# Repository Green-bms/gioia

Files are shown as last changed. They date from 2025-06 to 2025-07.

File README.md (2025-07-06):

# Gioia - glittering fashion
Electronic wearable device <br> 
<br> 
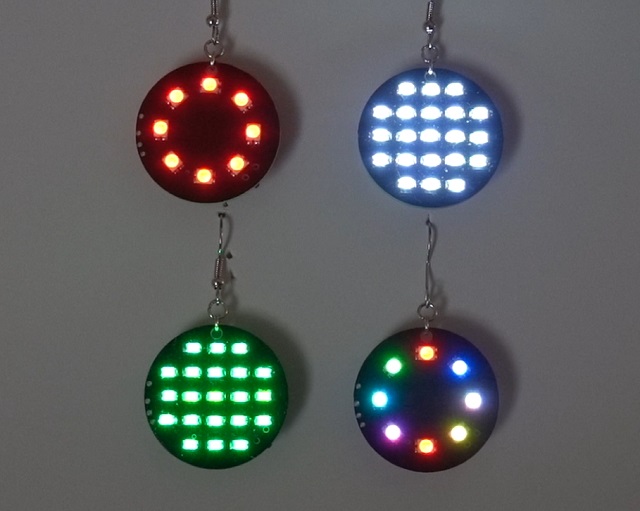
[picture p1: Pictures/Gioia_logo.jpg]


Youtube: https://youtu.be/MnyeiMZdmjQ?si=YpLxnYz4cA8ocs8j <br> 
Instructables: https://www.instructables.com/Gioia-Glittering-Fashion/ <br> 
Hackaday.io: https://hackaday.io/project/202226-gioia-glittering-fashion <br> 
Hackster.io: https://www.hackster.io/green-bms/gioia-glittering-fashion-81f5f8 <br> 
Purchase PCB here: <br> 
https://www.pcbway.com/project/shareproject/Gioia_glittering_fashion_21_monocrome_leds_caeb9192.html  <br>
https://www.pcbway.com/project/shareproject/Gioia_glittering_fashion_8_RGB_leds_abd15673.html <br>

## Description
"Gioia" in Italian means joy.<br> 
I wanted to call this project this way in the hope that it will bring joy and happiness to those who wear it.<br> 
This gadget of 3 cm of diametrer can contain a maximum of 24 single-color LEDs or 8 RGB LEDs.<br> 
The infinite animations, which also include letters and symbols, are managed by an Attiny85 microcontroller.<br> 

### The PCB
Gioia's PCBs are made by PCBway https://pcbway.com/g/kY6w10 <br>
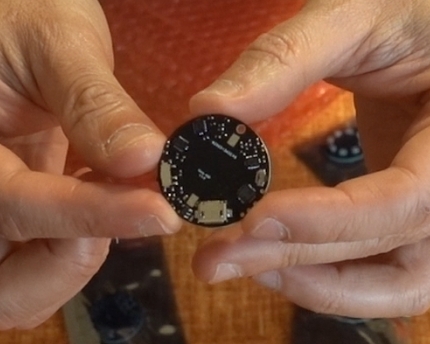
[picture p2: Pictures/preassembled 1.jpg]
 <br>
I chose this supplier because the quality of the PCB and the assembly of the components is of great quality.
The assistance is excellent and the delivery times are always respected <br>
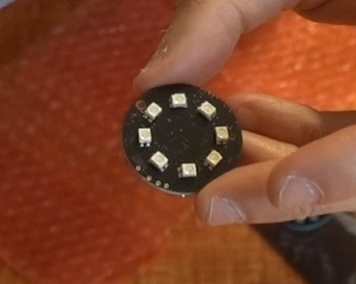
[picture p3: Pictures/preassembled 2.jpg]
 <br>

### Battery
The device is powered by a 30mAh LIR1632 rechargeable lithium battery. <br>
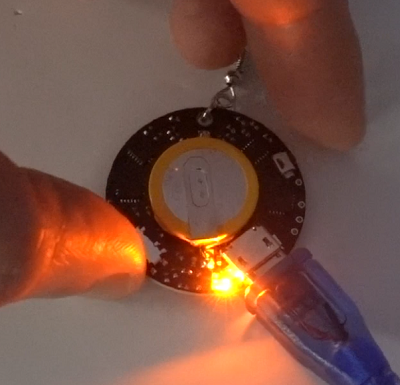
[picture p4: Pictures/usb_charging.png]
 <br> 
Charging is done via a micro USB connector and takes about 90 minutes from 0% to 100%
The device lasts for about 5 continuous hours

### Versions
The project is available in 2 versions:<br>

#### 21 monochrome leds:<br>
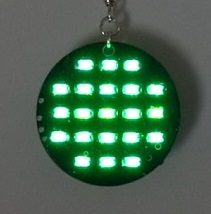
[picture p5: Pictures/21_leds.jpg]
 <br> 
All the documentation to make it is available here: https://github.com/Green-bms/gioia/tree/master/21%20monochrome%20leds%20version

#### 8 RGB leds:<br>
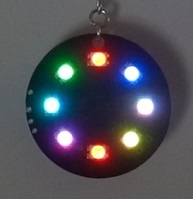
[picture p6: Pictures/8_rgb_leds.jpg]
 <br> 
Each LED can light up in one of these 7 colors: red, green, blue, yellow, fuchsia, aqua, white. <br>
All the documentation to make it is available here: https://github.com/Green-bms/gioia/tree/master/8%20RGB%20leds%20version

### Microcontroller
The device's LEDs are driven by an Attiny85 microcontroller and 3 74HC595 shift registers.<br> 
The LED animations that can compose various light games, texts and symbols, are programmed in the code to be loaded into the microcontroller<br> 
Programming the microcontroller is very simple: you need to power the device via USB and connect the 4 pins of the ISP programmer to the pads shown in the pictures below.<br> 
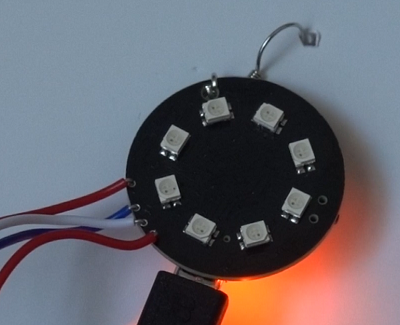
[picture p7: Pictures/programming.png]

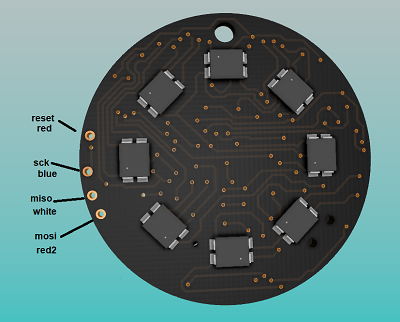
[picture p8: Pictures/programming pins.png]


## Open source Development applications
The project was created using the following Open source applications:
- **KiCad** : to design pcb
- **Arduino IDE** : to design the code for Attiny85 microcontroller of device animations

## Warning
This project is not commercial. This project is for educational and technological purposes.
No warrenty is foreseen.
Green BMS assumes no responsibility for any errors or inaccuracies that may appear in any documentation or file or any software that may be provided.
The use of this project is done entirely at your own risk and responsibility.
The use of this project may not be compliant with local laws or regulations.

## License

This work is licensed under a **Creative Commons Attribution-ShareAlike 4.0 International License**.
https://creativecommons.org/licenses/by-sa/4.0/

### You are free to:

**Share** — copy and redistribute the material in any medium or format

**Adapt**  — remix, transform, and build upon the material
for any purpose, even commercially.
This license is acceptable for Free Cultural Works.
The licensor cannot revoke these freedoms as long as you follow the license terms.

### Under the following terms:

**Attribution** — You must give appropriate credit, provide a link to the license, and indicate if changes were made. You may do so in any reasonable manner, but not in any way that suggests the licensor endorses you or your use.

**ShareAlike** — If you remix, transform, or build upon the material, you must distribute your contributions under the same license as the original.

**No additional restrictions** — You may not apply legal terms or technological measures that legally restrict others from doing anything the license permits.

### Notices:
You do not have to comply with the license for elements of the material in the public domain or where your use is permitted by an applicable exception or limitation.
No warranties are given. The license may not give you all of the permissions necessary for your intended use. For example, other rights such as publicity, privacy, or moral rights may limit how you use the material.

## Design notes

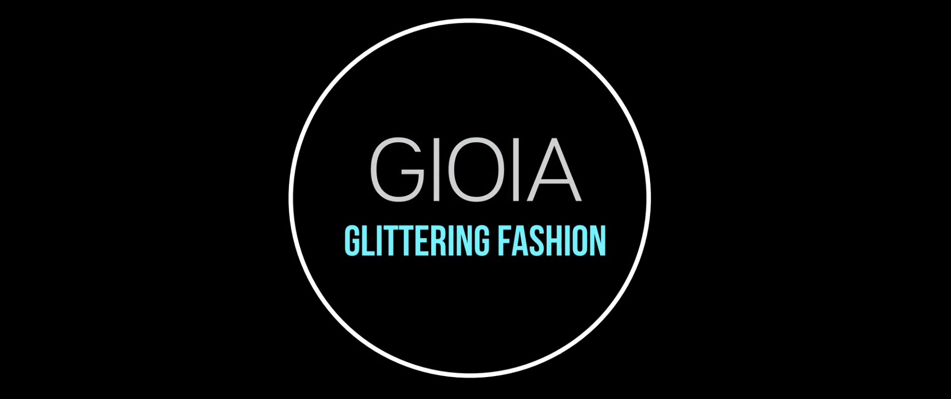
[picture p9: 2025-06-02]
21 monochrome leds version/Kicad files/cartiglio/Immagine.png

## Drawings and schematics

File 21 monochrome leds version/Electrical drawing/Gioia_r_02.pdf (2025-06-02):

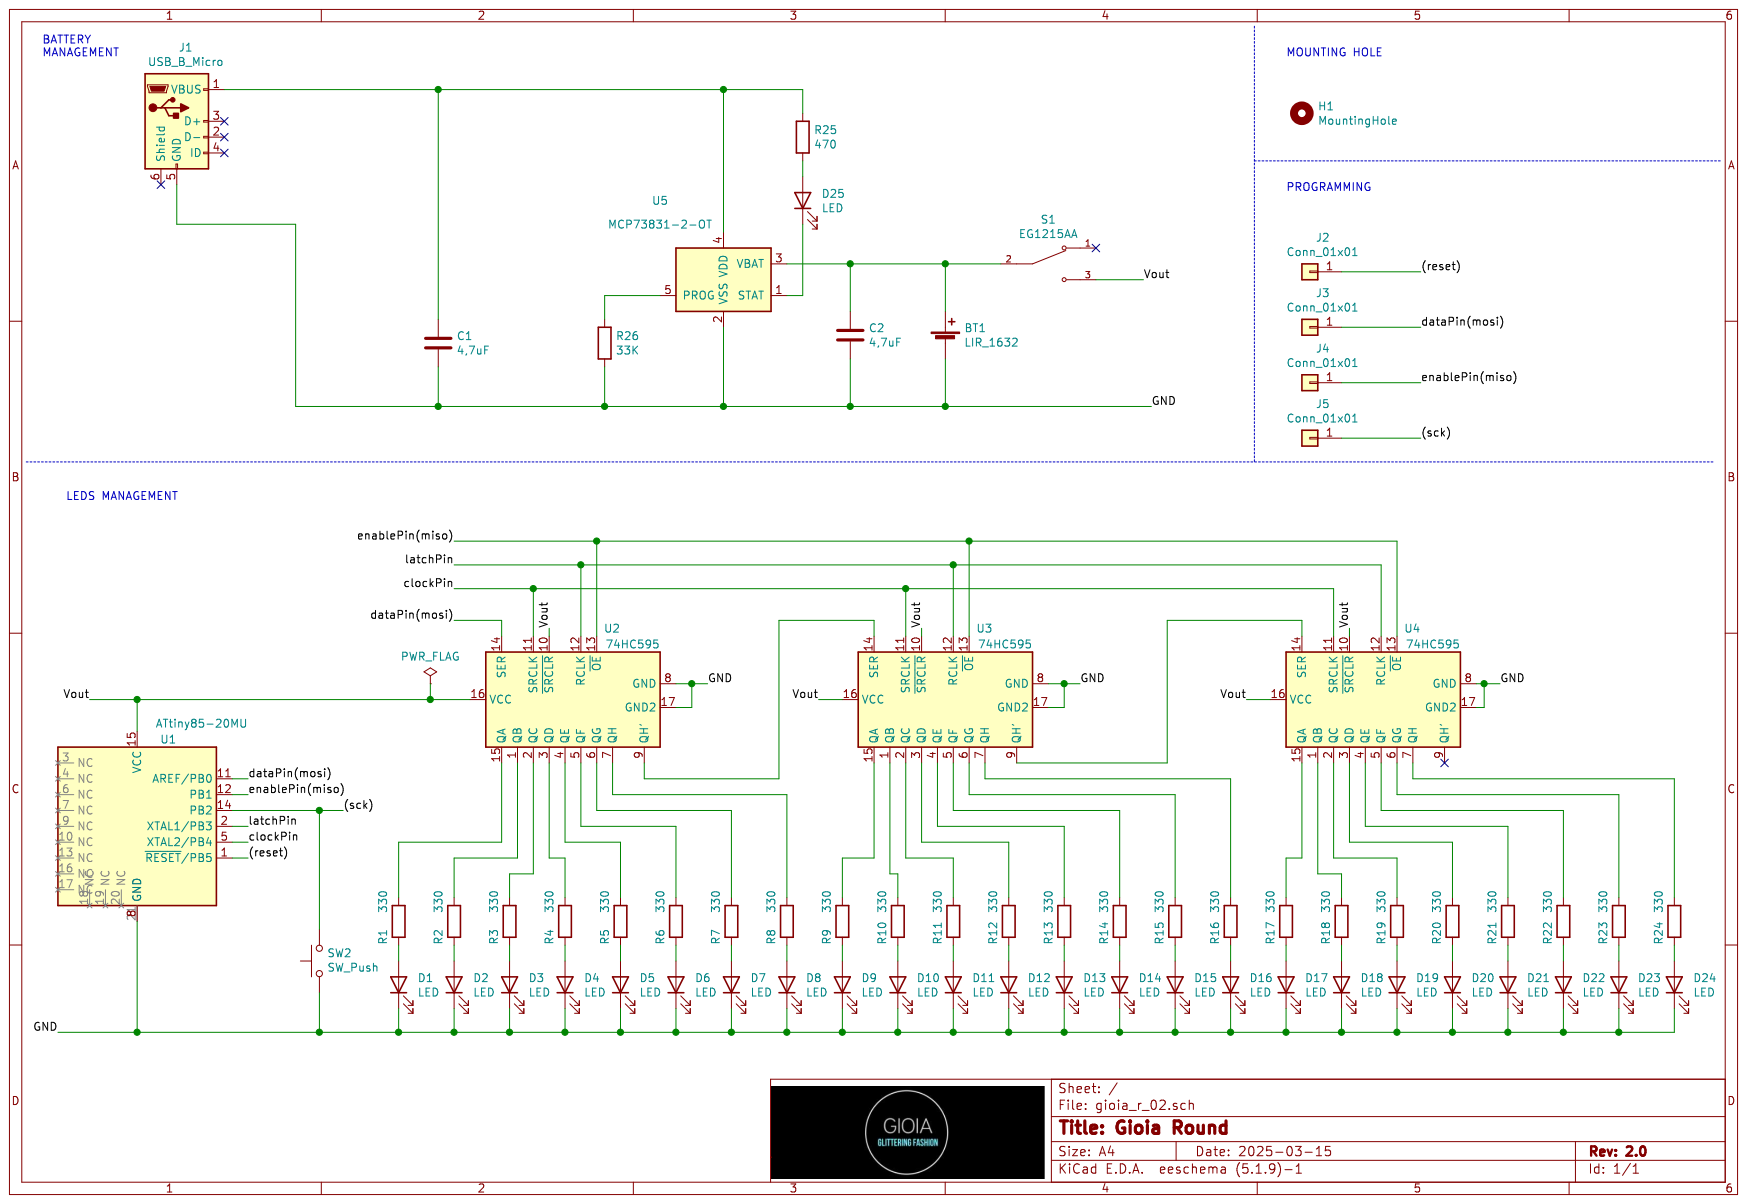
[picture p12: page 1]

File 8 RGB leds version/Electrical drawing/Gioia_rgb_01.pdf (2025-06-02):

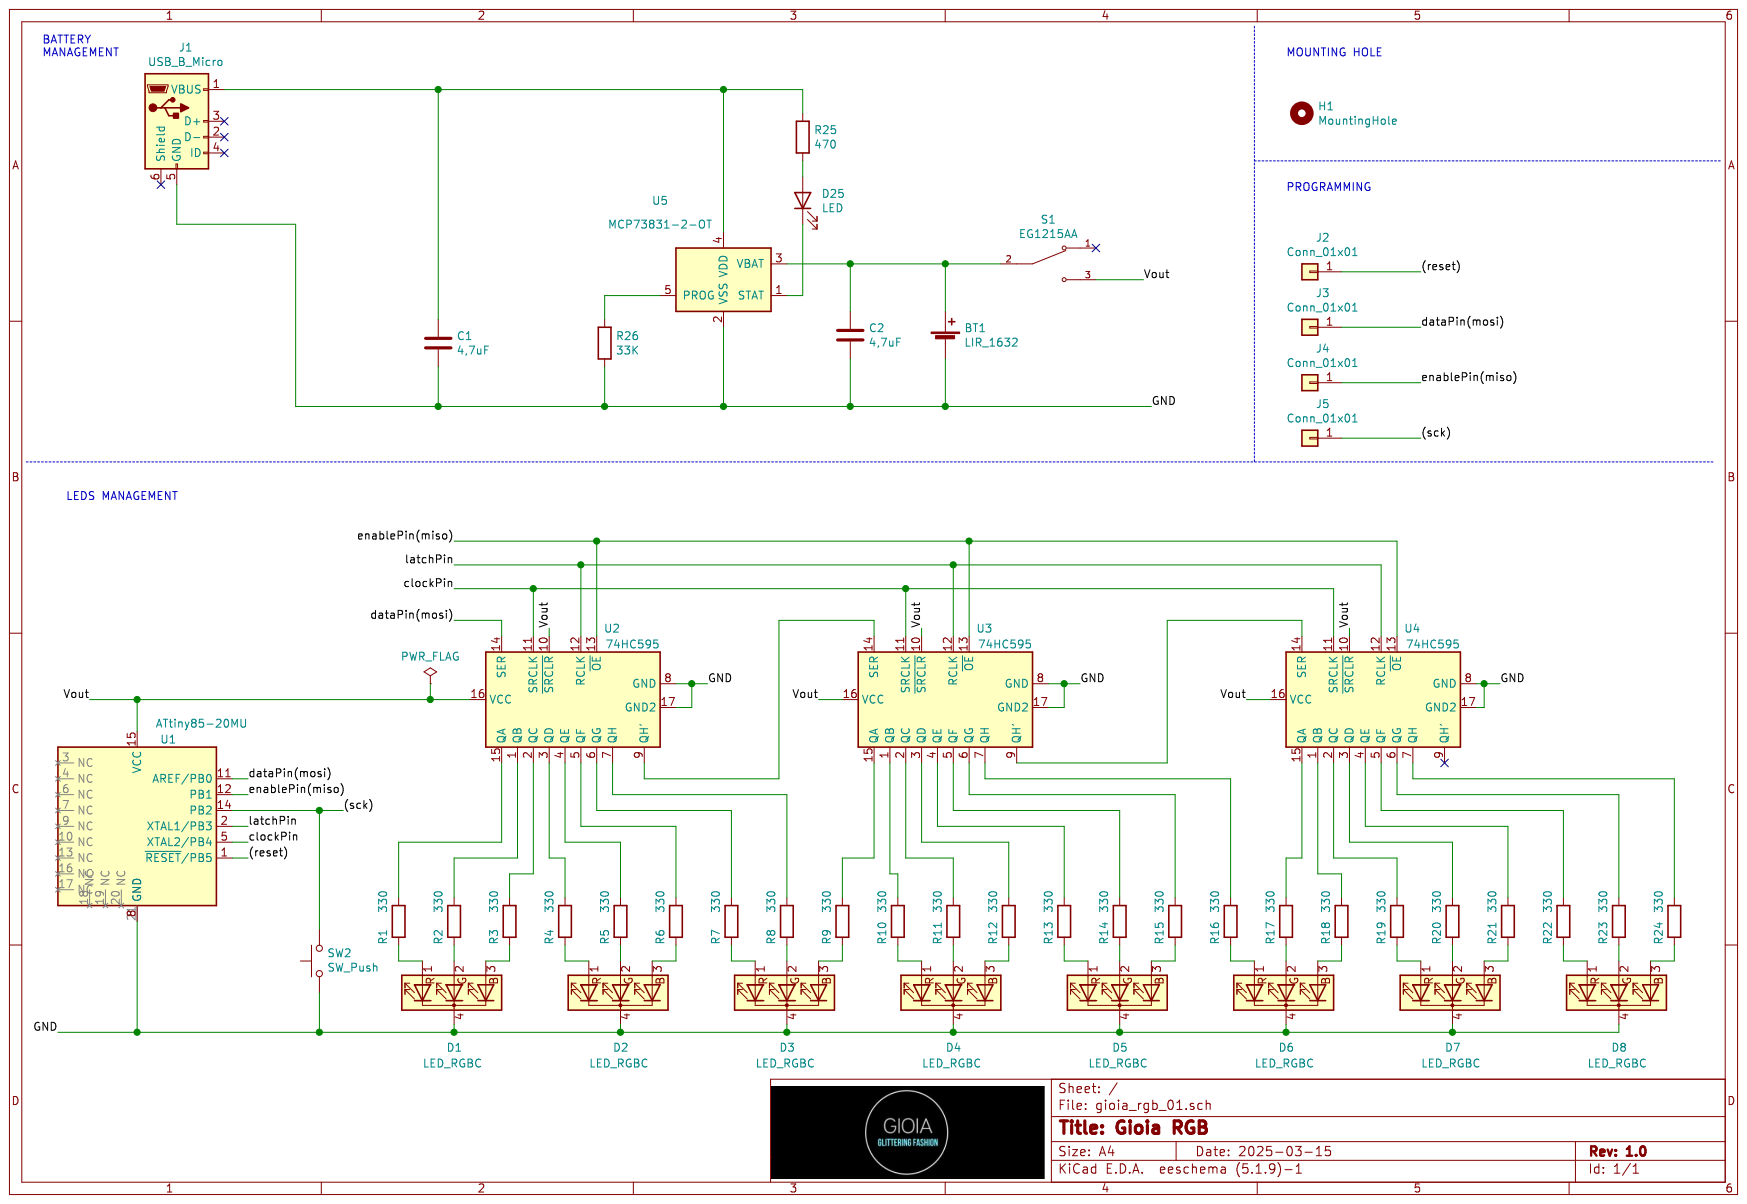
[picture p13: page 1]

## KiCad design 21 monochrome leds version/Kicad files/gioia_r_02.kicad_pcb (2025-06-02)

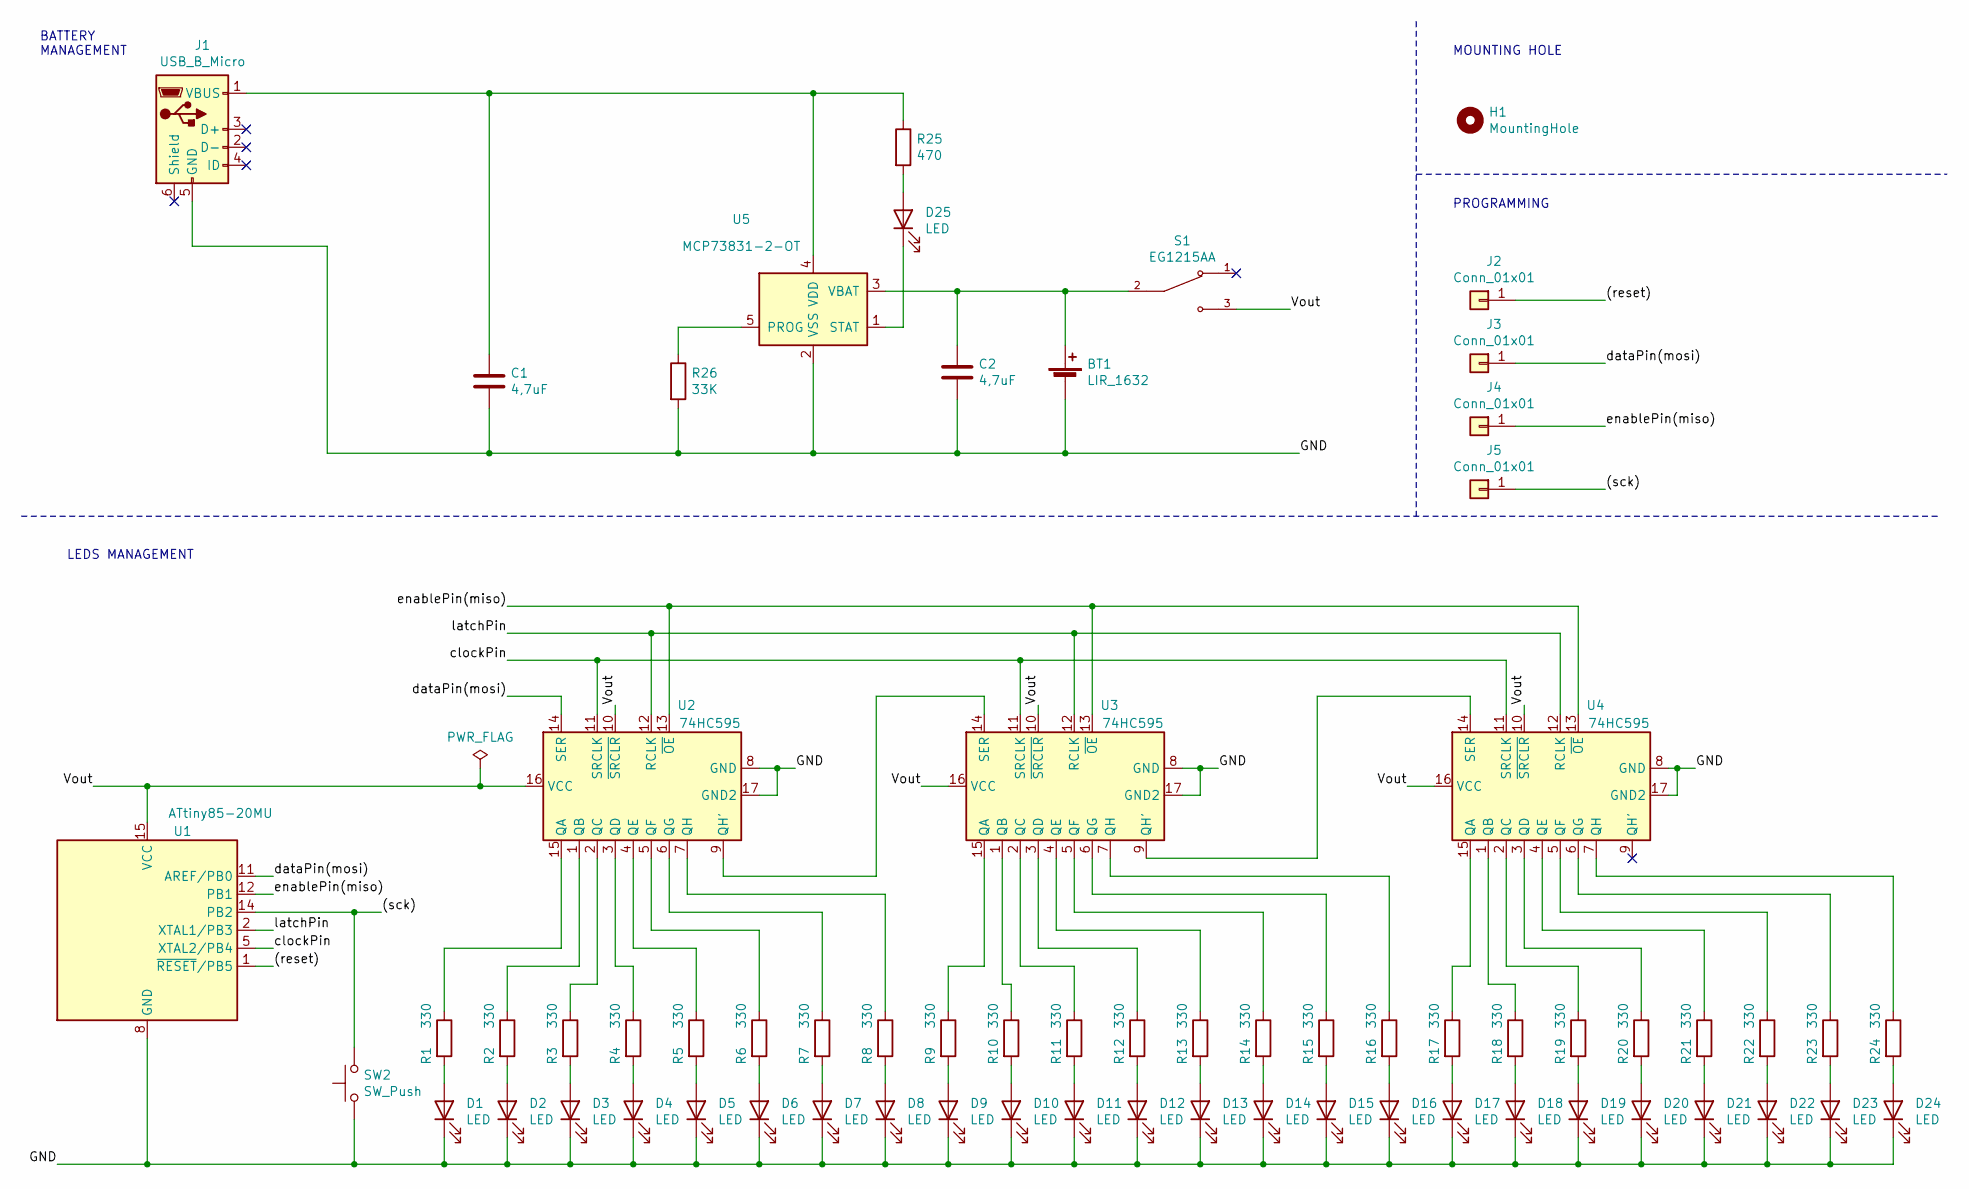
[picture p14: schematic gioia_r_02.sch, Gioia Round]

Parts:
BT1: LIR_1632; LIR1632_SMD
C1, C2: 4,7uF; C_0402_1005Metric
D1, D2, D3, D4, D5, D6, D7, D8, D9, D10, D11, D12, D13, D14, D15, D16, D17, D18, D19, D20, D21, D22, D23, D24: LED; LED_1206_3216Metric
D25: LED; LED_0402_1005Metric
H1: MountingHole; MountingHole_2.1mm
J1: USB_B_Micro; USB_Micro-B_Amphenol_10104110_Horizontal
J2, J3, J4, J5: Conn_01x01; TestPoint_THTPad_D1.0mm_Drill0.6mm
R1, R2, R3, R4, R5, R6, R7, R8, R9, R10, R11, R12, R13, R14, R15, R16, R17, R18, R19, R20, R21, R22, R23, R24: 330; R_0402_1005Metric
R25: 470; R_0402_1005Metric
R26: 33K; R_0402_1005Metric
S1: EG1215AA; SW_EG1215AA; PARTREV A
SW2: SW_Push; SW_SPST_B3U-3000P
U1: ATtiny85-20MU; QFN-20-1EP_4x4mm_P0.5mm_EP2.6x2.6mm
U2, U3, U4: 74HC595; DHVQFN16
U5: MCP73831-2-OT; SOT-23-5

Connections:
/(reset): J2.1, U1.1 (~RESET~/PB5)
/(sck): J5.1, SW2.2, U1.14 (PB2)
/GND: BT1.2 (-), C1.2, C2.2, D1.1 (K), D2.1 (K), D3.1 (K), D4.1 (K), D5.1 (K), D6.1 (K), D7.1 (K), D8.1 (K), D9.1 (K), D10.1 (K), D11.1 (K), D12.1 (K), D13.1 (K), D14.1 (K), D15.1 (K), D16.1 (K), D17.1 (K), D18.1 (K), D19.1 (K), D20.1 (K), D21.1 (K), D22.1 (K), D23.1 (K), D24.1 (K), J1.5 (GND), R26.2, SW2.1, U1.8 (GND), U1.21 (GND), U2.8 (GND), U2.17 (GND2), U3.8 (GND), U3.17 (GND2), U4.8 (GND), U4.17 (GND2), U5.2 (VSS)
/Vout: S1.3, U1.15 (VCC), U2.10 (~SRCLR), U2.16 (VCC), U3.10 (~SRCLR), U3.16 (VCC), U4.10 (~SRCLR), U4.16 (VCC)
/clockPin: U1.5 (XTAL2/PB4), U2.11 (SRCLK), U3.11 (SRCLK), U4.11 (SRCLK)
/dataPin(mosi): J3.1, U1.11 (AREF/PB0), U2.14 (SER)
/enablePin(miso): J4.1, U1.12 (PB1), U2.13 (~OE), U3.13 (~OE), U4.13 (~OE)
/latchPin: U1.2 (XTAL1/PB3), U2.12 (RCLK), U3.12 (RCLK), U4.12 (RCLK)
unnamed: BT1.1 (+), C2.1, S1.2, U5.3 (VBAT)
unnamed: C1.1, J1.1 (VBUS), R25.1, U5.4 (VDD)
unnamed: D1.2 (A), R1.2
unnamed: D2.2 (A), R2.2
unnamed: D3.2 (A), R3.2
unnamed: D4.2 (A), R4.2
unnamed: D5.2 (A), R5.2
unnamed: D6.2 (A), R6.2
unnamed: D7.2 (A), R7.2
unnamed: D8.2 (A), R8.2
unnamed: D9.2 (A), R9.2
unnamed: D10.2 (A), R10.2
unnamed: D11.2 (A), R11.2
unnamed: D12.2 (A), R12.2
unnamed: D13.2 (A), R13.2
unnamed: D14.2 (A), R14.2
unnamed: D15.2 (A), R15.2
unnamed: D16.2 (A), R16.2
unnamed: D17.2 (A), R17.2
unnamed: D18.2 (A), R18.2
unnamed: D19.2 (A), R19.2
unnamed: D20.2 (A), R20.2
unnamed: D21.2 (A), R21.2
unnamed: D22.2 (A), R22.2
unnamed: D23.2 (A), R23.2
unnamed: D24.2 (A), R24.2
unnamed: D25.1 (K), U5.1 (STAT)
unnamed: D25.2 (A), R25.2
unnamed: R1.1, U2.15 (QA)
unnamed: R2.1, U2.1 (QB)
unnamed: R3.1, U2.2 (QC)
unnamed: R4.1, U2.3 (QD)
unnamed: R5.1, U2.4 (QE)
unnamed: R6.1, U2.5 (QF)
unnamed: R7.1, U2.6 (QG)
unnamed: R8.1, U2.7 (QH)
unnamed: R9.1, U3.15 (QA)
unnamed: R10.1, U3.1 (QB)
unnamed: R11.1, U3.2 (QC)
unnamed: R12.1, U3.3 (QD)
unnamed: R13.1, U3.4 (QE)
unnamed: R14.1, U3.5 (QF)
unnamed: R15.1, U3.6 (QG)
unnamed: R16.1, U3.7 (QH)
unnamed: R17.1, U4.15 (QA)
unnamed: R18.1, U4.1 (QB)
unnamed: R19.1, U4.2 (QC)
unnamed: R20.1, U4.3 (QD)
unnamed: R21.1, U4.4 (QE)
unnamed: R22.1, U4.5 (QF)
unnamed: R23.1, U4.6 (QG)
unnamed: R24.1, U4.7 (QH)
unnamed: R26.1, U5.5 (PROG)
unnamed: U2.9 (QH'), U3.14 (SER)
unnamed: U3.9 (QH'), U4.14 (SER)

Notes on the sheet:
BATTERY MANAGEMENT
MOUNTING HOLE
LEDS MANAGEMENT
PROGRAMMING

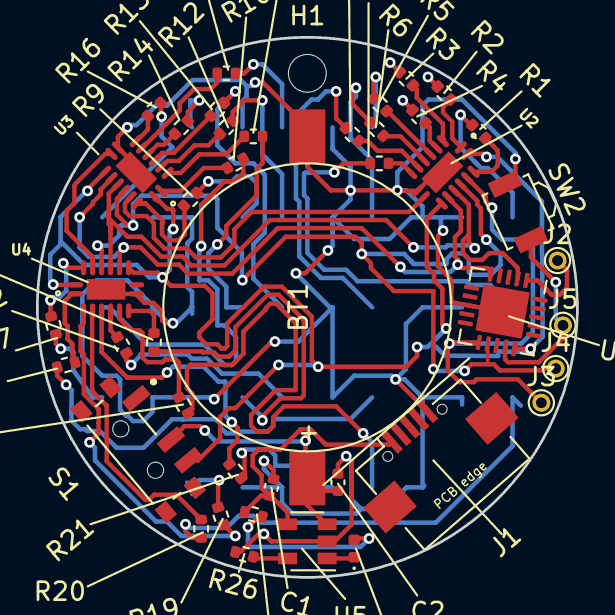
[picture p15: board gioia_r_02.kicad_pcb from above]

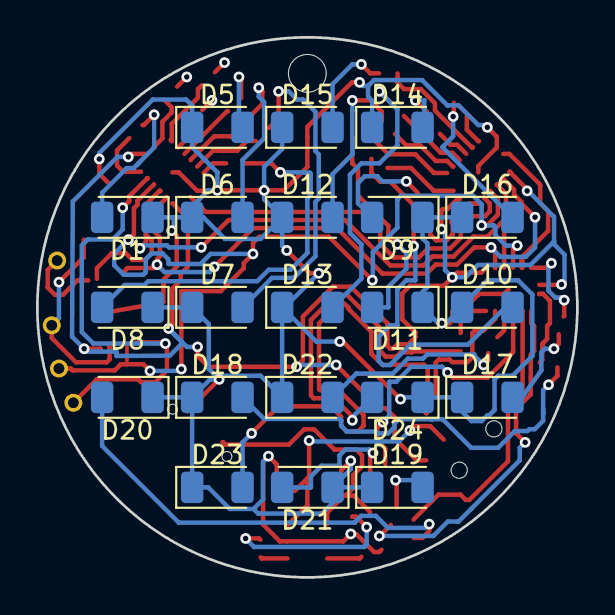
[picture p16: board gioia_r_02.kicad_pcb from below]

Board: 2 copper layers, 30.0 x 30.0 mm, 64 parts (21 on the bottom side), 60 nets.

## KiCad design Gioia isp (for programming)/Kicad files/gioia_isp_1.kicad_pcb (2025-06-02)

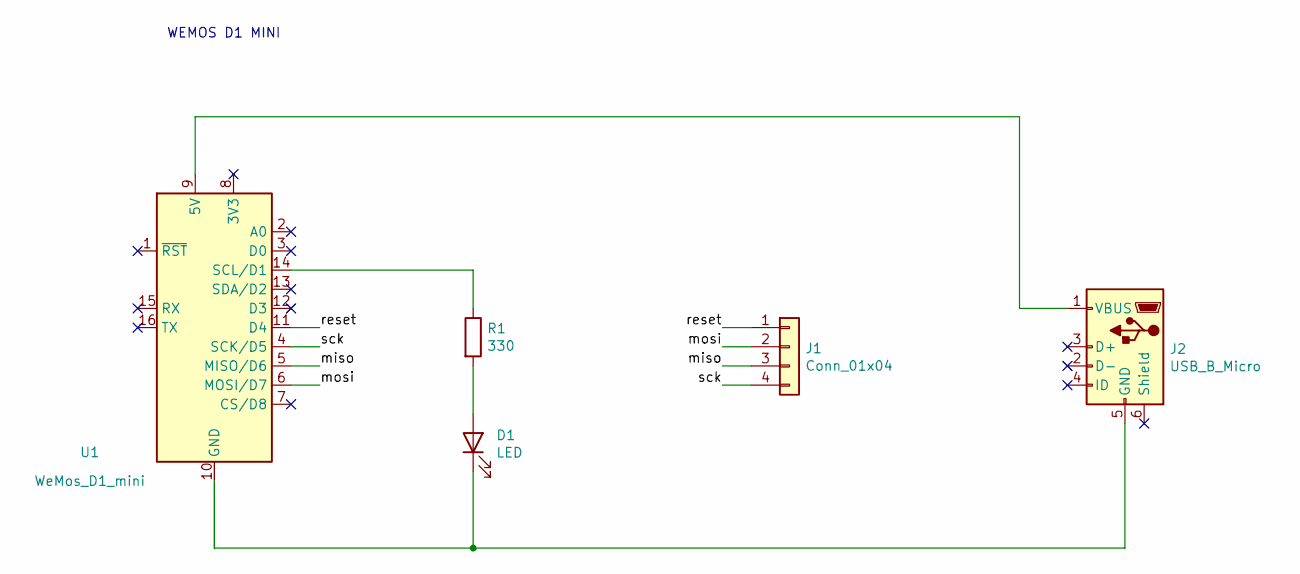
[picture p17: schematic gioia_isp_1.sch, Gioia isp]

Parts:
D1: LED; LED_D3.0mm
J1: Conn_01x04; PinSocket_1x04_P2.54mm_Vertical
J2: USB_B_Micro; USB_Micro-B_Amphenol_10104110_Horizontal
R1: 330; R_Axial_DIN0207_L6.3mm_D2.5mm_P2.54mm_Vertical
U1: WeMos_D1_mini; WEMOS_D1_mini_light

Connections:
/miso: J1.3, U1.5 (MISO/D6)
/mosi: J1.2, U1.6 (MOSI/D7)
/reset: J1.1, U1.11 (D4)
/sck: J1.4, U1.4 (SCK/D5)
unnamed: D1.1 (K), J2.5 (GND), U1.10 (GND)
unnamed: D1.2 (A), R1.2
unnamed: J2.1 (VBUS), U1.9 (5V)
unnamed: R1.1, U1.14 (SCL/D1)

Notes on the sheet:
WEMOS D1 MINI

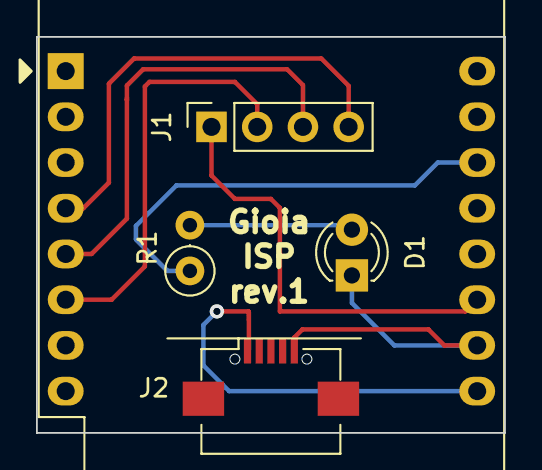
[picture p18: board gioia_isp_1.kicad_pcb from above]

Board: 2 copper layers, 26.0 x 22.0 mm, 5 parts (0 on the bottom side), 8 nets.

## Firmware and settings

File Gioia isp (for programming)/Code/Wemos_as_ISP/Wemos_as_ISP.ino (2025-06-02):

//Wemos_as_ISP
//forked from vince-br-549/ESP8266-as-ISP
// first release on 2024-02-26 by Sergio Ghirardelli
// - modified reset pin configuration using GPIO number
// - added programing led output


/*
 * 2018-5-10 vince
 * to get it to work on WEMOS D1 Mini I dummied out the status LEDs
 * RESET is D4
 * He set up to use hardware spi and added include for spi.h
 * 
 */

 
// ArduinoISP
// Copyright (c) 2008-2011 Randall Bohn
// small changes for the ESP32 by pcbreflux and vince
// If you require a license, see
// http://www.opensource.org/licenses/bsd-license.php
//
// This sketch turns the Arduino into a AVRISP using the following Arduino pins:
//
// Pin D4 is used to reset the target microcontroller.
//
// By default, the hardware SPI pins MISO, MOSI and SCK are used to communicate
// with the target. On all Arduinos, these pins can be found
// on the ICSP/SPI header:
//
//               MISO °. . 5V (!) Avoid this pin on Due, Zero...
//               SCK   . . MOSI
//                     . . GND
//
// On some Arduinos (Uno,...), pins MOSI, MISO and SCK are the same pins as
// digital pin 11, 12 and 13, respectively. That is why many tutorials instruct
// you to hook up the target to these pins. If you find this wiring more
// practical, have a define USE_OLD_STYLE_WIRING. This will work even when not
// using an Uno. (On an Uno this is not needed).
//
// Alternatively you can use any other digital pin by configuring
// software ('BitBanged') SPI and having appropriate defines for PIN_MOSI,
// PIN_MISO and PIN_SCK.
//
// IMPORTANT: When using an Arduino that is not 5V tolerant (Due, Zero, ...) as
// the programmer, make sure to not expose any of the programmer's pins to 5V.
// A simple way to accomplish this is to power the complete system (programmer
// and target) at 3V3.
//
// Put an LED (with resistor) on the following pins:
// 9: Heartbeat   - shows the programmer is running
// 8: Error       - Lights up if something goes wrong (use red if that makes sense)
// 7: Programming - In communication with the slave
//

#include "Arduino.h"
#undef SERIAL


#define PROG_FLICKER true

// Configure SPI clock (in Hz).
// E.g. for an ATtiny @ 128 kHz: the datasheet states that both the high and low
// SPI clock pulse must be > 2 CPU cycles, so take 3 cycles i.e. divide target
// f_cpu by 6:
//     #define SPI_CLOCK            (128000/6)
//
// A clock slow enough for an ATtiny85 @ 1 MHz, is a reasonable default:
#define SPI_CLOCK     (128000/6)
//#define SPI_CLOCK     (1000000/6)


// Select hardware or software SPI, depending on SPI clock.
// Currently only for AVR, for other architectures (Due, Zero,...), hardware SPI
// is probably too fast anyway.

#if defined(ARDUINO_ARCH_AVR)

#if SPI_CLOCK > (F_CPU / 128)
#define USE_HARDWARE_SPI
#endif

#endif

// Configure which pins to use:

// The standard pin configuration.
#ifndef ARDUINO_HOODLOADER2
#define RESET     2  // modified with GPIO number
//#define LED_HB    9
//#define LED_ERR   8
//#define LED_PMODE 7

// Uncomment following line to use the old Uno style wiring
// (using pin 11, 12 and 13 instead of the SPI header) on Leonardo, Due...

// #define USE_OLD_STYLE_WIRING

#ifdef USE_OLD_STYLE_WIRING

#define PIN_MOSI  11
#define PIN_MISO  12
#define PIN_SCK   13

#endif

// HOODLOADER2 means running sketches on the ATmega16U2 serial converter chips
// on Uno or Mega boards. We must use pins that are broken out:
#else

#define RESET       4
#define LED_HB      7
#define LED_ERR     6
#define LED_PMODE   5

#endif

// By default, use hardware SPI pins:
#ifndef PIN_MOSI
#define PIN_MOSI  MOSI
#endif

#ifndef PIN_MISO
#define PIN_MISO  MISO
#endif

#ifndef PIN_SCK
#define PIN_SCK   SCK
#endif

// Force bitbanged SPI if not using the hardware SPI pins:
#if (PIN_MISO != MISO) ||  (PIN_MOSI != MOSI) || (PIN_SCK != SCK)
#undef USE_HARDWARE_SPI
#endif


// Configure the serial port to use.
//
// Prefer the USB virtual serial port (aka. native USB port), if the Arduino has one:
//   - it does not autoreset (except for the magic baud rate of 1200).
//   - it is more reliable because of USB handshaking.
//
// Leonardo and similar have an USB virtual serial port: 'Serial'.
// Due and Zero have an USB virtual serial port: 'SerialUSB'.
//
// On the Due and Zero, 'Serial' can be used too, provided you disable autoreset.
// To use 'Serial': #define SERIAL Serial

#ifdef SERIAL_PORT_USBVIRTUAL
#define SERIAL SERIAL_PORT_USBVIRTUAL
#else
#define SERIAL Serial
#endif


// Configure the baud rate:

#define BAUDRATE  19200
// #define BAUDRATE 115200
// #define BAUDRATE 1000000


#define HWVER 2
#define SWMAJ 1
#define SWMIN 18

// STK Definitions
#define STK_OK      0x10
#define STK_FAILED  0x11
#define STK_UNKNOWN 0x12
#define STK_INSYNC  0x14
#define STK_NOSYNC  0x15
#define CRC_EOP     0x20 //ok it is a space...

void pulse(int pin, int times);
#define USE_HARDWARE_SPI

#ifdef USE_HARDWARE_SPI
#include "SPI.h"
#else

#define SPI_MODE0 0x00

class SPISettings {
  public:
    // clock is in Hz
    SPISettings(uint32_t clock, uint8_t bitOrder, uint8_t dataMode) : clock(clock) {
      (void) bitOrder;
      (void) dataMode;
    };

  private:
    uint32_t clock;

    friend class BitBangedSPI;
};

class BitBangedSPI {
  public:
    void begin() {
      digitalWrite(PIN_SCK, LOW);
      digitalWrite(PIN_MOSI, LOW);
      pinMode(PIN_SCK, OUTPUT);
      pinMode(PIN_MOSI, OUTPUT);
      pinMode(PIN_MISO, INPUT);
    }

    void beginTransaction(SPISettings settings) {
      pulseWidth = (500000 + settings.clock - 1) / settings.clock;
      if (pulseWidth == 0)
        pulseWidth = 1;
    }

    void end() {}

    uint8_t transfer (uint8_t b) {
      for (unsigned int i = 0; i < 8; ++i) {
        digitalWrite(PIN_MOSI, (b & 0x80) ? HIGH : LOW);
        digitalWrite(PIN_SCK, HIGH);
        delayMicroseconds(pulseWidth);
        b = (b << 1) | digitalRead(PIN_MISO);
        digitalWrite(PIN_SCK, LOW); // slow pulse
        delayMicroseconds(pulseWidth);
      }
      return b;
    }

  private:
    unsigned long pulseWidth; // in microseconds
};

static BitBangedSPI SPI;

#endif

void setup() {
  SERIAL.begin(BAUDRATE);
  pinMode(5, OUTPUT);

#ifdef LED_PMODE
  pinMode(LED_PMODE, OUTPUT);
  pulse(LED_PMODE, 2);
#endif
#ifdef LED_ERR
  pinMode(LED_ERR, OUTPUT);
  pulse(LED_ERR, 2);
#endif
#ifdef LED_HB
  pinMode(LED_HB, OUTPUT);
  pulse(LED_HB, 2);
#endif
}

int error = 0;
int pmode = 0;
// address for reading and writing, set by 'U' command
unsigned int here;
uint8_t buff[256]; // global block storage

#define beget16(addr) (*addr * 256 + *(addr+1) )
typedef struct param {
  uint8_t devicecode;
  uint8_t revision;
  uint8_t progtype;
  uint8_t parmode;
  uint8_t polling;
  uint8_t selftimed;
  uint8_t lockbytes;
  uint8_t fusebytes;
  uint8_t flashpoll;
  uint16_t eeprompoll;
  uint16_t pagesize;
  uint16_t eepromsize;
  uint32_t flashsize;
}
parameter;

parameter param;

// this provides a heartbeat on pin 9, so you can tell the software is running.
uint8_t hbval = 128;
int8_t hbdelta = 8;
void heartbeat() {
  static unsigned long last_time = 0;
  unsigned long now = millis();
  if ((now - last_time) < 40)
    return;
  last_time = now;
  if (hbval > 192) hbdelta = -hbdelta;
  if (hbval < 32) hbdelta = -hbdelta;
  hbval += hbdelta;
  //analogWrite(LED_HB, hbval);
}

static bool rst_active_high;

void reset_target(bool reset) {
  digitalWrite(RESET, ((reset && rst_active_high) || (!reset && !rst_active_high)) ? HIGH : LOW);
}

void loop(void) {
  // is pmode active?
#ifdef LED_PMODE
  if (pmode) {
    digitalWrite(LED_PMODE, HIGH);
  } else {
    digitalWrite(LED_PMODE, LOW);
  }
#endif
  // is there an error?
#ifdef LED_ERR
  if (error) {
    digitalWrite(LED_ERR, HIGH);
  } else {
    digitalWrite(LED_ERR, LOW);
  }
#endif
  // light the heartbeat LED
  heartbeat();
  if (SERIAL.available()) {
    avrisp();
  }
  if (pmode) {digitalWrite(5, HIGH); } // wemos as isp board led
  else {digitalWrite(5, LOW); } // wemos as isp board led
  
 
}

uint8_t getch() {
  while (!SERIAL.available());
  return SERIAL.read();
}
void fill(int n) {
  for (int x = 0; x < n; x++) {
    buff[x] = getch();
  }
}

#define PTIME 30
void pulse(int pin, int times) {
  do {
    digitalWrite(pin, HIGH);
    delay(PTIME);
    digitalWrite(pin, LOW);
    delay(PTIME);
  } while (times--);
}

void prog_lamp(int state) {
  if (PROG_FLICKER) {
#ifdef LED_PMODE
    digitalWrite(LED_PMODE, state);
#endif
  }
}

uint8_t spi_transaction(uint8_t a, uint8_t b, uint8_t c, uint8_t d) {
  SPI.transfer(a);
  SPI.transfer(b);
  SPI.transfer(c);
  return SPI.transfer(d);
}

void empty_reply() {
  if (CRC_EOP == getch()) {
    SERIAL.print((char)STK_INSYNC);
    SERIAL.print((char)STK_OK);
  } else {
    error++;
    SERIAL.print((char)STK_NOSYNC);
  }
}

void breply(uint8_t b) {
  if (CRC_EOP == getch()) {
    SERIAL.print((char)STK_INSYNC);
    SERIAL.print((char)b);
    SERIAL.print((char)STK_OK);
  } else {
    error++;
    SERIAL.print((char)STK_NOSYNC);
  }
}

void get_version(uint8_t c) {
  switch (c) {
    case 0x80:
      breply(HWVER);
      break;
    case 0x81:
      breply(SWMAJ);
      break;
    case 0x82:
      breply(SWMIN);
      break;
    case 0x93:
      breply('S'); // serial programmer
      break;
    default:
      breply(0);
  }
}

void set_parameters() {
  // call this after reading parameter packet into buff[]
  param.devicecode = buff[0];
  param.revision   = buff[1];
  param.progtype   = buff[2];
  param.parmode    = buff[3];
  param.polling    = buff[4];
  param.selftimed  = buff[5];
  param.lockbytes  = buff[6];
  param.fusebytes  = buff[7];
  param.flashpoll  = buff[8];
  // ignore buff[9] (= buff[8])
  // following are 16 bits (big endian)
  param.eeprompoll = beget16(&buff[10]);
  param.pagesize   = beget16(&buff[12]);
  param.eepromsize = beget16(&buff[14]);

  // 32 bits flashsize (big endian)
  param.flashsize = buff[16] * 0x01000000
                    + buff[17] * 0x00010000
                    + buff[18] * 0x00000100
                    + buff[19];

  // AVR devices have active low reset, AT89Sx are active high
  rst_active_high = (param.devicecode >= 0xe0);
}

void start_pmode() {

  // Reset target before driving PIN_SCK or PIN_MOSI

  // SPI.begin() will configure SS as output, so SPI master mode is selected.
  // We have defined RESET as pin 10, which for many Arduinos is not the SS pin.
  // So we have to configure RESET as output here,
  // (reset_target() first sets the correct level)
  reset_target(true);
  pinMode(RESET, OUTPUT);
  SPI.begin();
  SPI.beginTransaction(SPISettings(SPI_CLOCK, MSBFIRST, SPI_MODE0));

  // See AVR datasheets, chapter "SERIAL_PRG Programming Algorithm":

  // Pulse RESET after PIN_SCK is low:
  digitalWrite(PIN_SCK, LOW);
  delay(20); // discharge PIN_SCK, value arbitrarily chosen
  reset_target(false);
  // Pulse must be minimum 2 target CPU clock cycles so 100 usec is ok for CPU
  // speeds above 20 KHz
  delayMicroseconds(100);
  reset_target(true);

  // Send the enable programming command:
  delay(50); // datasheet: must be > 20 msec
  spi_transaction(0xAC, 0x53, 0x00, 0x00);
  pmode = 1;
}

void end_pmode() {
  SPI.end();
  // We're about to take the target out of reset so configure SPI pins as input
  pinMode(PIN_MOSI, INPUT);
  pinMode(PIN_SCK, INPUT);
  reset_target(false);
  pinMode(RESET, INPUT);
  pmode = 0;
}

void universal() {
  uint8_t ch;

  fill(4);
  ch = spi_transaction(buff[0], buff[1], buff[2], buff[3]);
  breply(ch);
}

void flash(uint8_t hilo, unsigned int addr, uint8_t data) {
  spi_transaction(0x40 + 8 * hilo,
                  addr >> 8 & 0xFF,
                  addr & 0xFF,
                  data);
}
void commit(unsigned int addr) {
  if (PROG_FLICKER) {
    prog_lamp(LOW);
  }
  spi_transaction(0x4C, (addr >> 8) & 0xFF, addr & 0xFF, 0);
  if (PROG_FLICKER) {
    delay(PTIME);
    prog_lamp(HIGH);
  }
}

unsigned int current_page() {
  if (param.pagesize == 32) {
    return here & 0xFFFFFFF0;
  }
  if (param.pagesize == 64) {
    return here & 0xFFFFFFE0;
  }
  if (param.pagesize == 128) {
    return here & 0xFFFFFFC0;
  }
  if (param.pagesize == 256) {
    return here & 0xFFFFFF80;
  }
  return here;
}


void write_flash(int length) {
  fill(length);
  if (CRC_EOP == getch()) {
    SERIAL.print((char) STK_INSYNC);
    SERIAL.print((char) write_flash_pages(length));
  } else {
    error++;
    SERIAL.print((char) STK_NOSYNC);
  }
}

uint8_t write_flash_pages(int length) {
  int x = 0;
  unsigned int page = current_page();
  while (x < length) {
    if (page != current_page()) {
      commit(page);
      page = current_page();
    }
    flash(LOW, here, buff[x++]);
    flash(HIGH, here, buff[x++]);
    here++;
  }

  commit(page);

  return STK_OK;
}

#define EECHUNK (32)
uint8_t write_eeprom(unsigned int length) {
  // here is a word address, get the byte address
  unsigned int start = here * 2;
  unsigned int remaining = length;
  if (length > param.eepromsize) {
    error++;
    return STK_FAILED;
  }
  while (remaining > EECHUNK) {
    write_eeprom_chunk(start, EECHUNK);
    start += EECHUNK;
    remaining -= EECHUNK;
  }
  write_eeprom_chunk(start, remaining);
  return STK_OK;
}
// write (length) bytes, (start) is a byte address
uint8_t write_eeprom_chunk(unsigned int start, unsigned int length) {
  // this writes byte-by-byte, page writing may be faster (4 bytes at a time)
  fill(length);
  prog_lamp(LOW);
  for (unsigned int x = 0; x < length; x++) {
    unsigned int addr = start + x;
    spi_transaction(0xC0, (addr >> 8) & 0xFF, addr & 0xFF, buff[x]);
    delay(45);
  }
  prog_lamp(HIGH);
  return STK_OK;
}

void program_page() {
  char result = (char) STK_FAILED;
  unsigned int length = 256 * getch();
  length += getch();
  char memtype = getch();
  // flash memory @here, (length) bytes
  if (memtype == 'F') {
    write_flash(length);
    return;
  }
  if (memtype == 'E') {
    result = (char)write_eeprom(length);
    if (CRC_EOP == getch()) {
      SERIAL.print((char) STK_INSYNC);
      SERIAL.print(result);
    } else {
      error++;
      SERIAL.print((char) STK_NOSYNC);
    }
    return;
  }
  SERIAL.print((char)STK_FAILED);
  return;
}

uint8_t flash_read(uint8_t hilo, unsigned int addr) {
  return spi_transaction(0x20 + hilo * 8,
                         (addr >> 8) & 0xFF,
                         addr & 0xFF,
                         0);
}

char flash_read_page(int length) {
  for (int x = 0; x < length; x += 2) {
    uint8_t low = flash_read(LOW, here);
    SERIAL.print((char) low);
    uint8_t high = flash_read(HIGH, here);
    SERIAL.print((char) high);
    here++;
  }
  return STK_OK;
}

char eeprom_read_page(int length) {
  // here again we have a word address
  int start = here * 2;
  for (int x = 0; x < length; x++) {
    int addr = start + x;
    uint8_t ee = spi_transaction(0xA0, (addr >> 8) & 0xFF, addr & 0xFF, 0xFF);
    SERIAL.print((char) ee);
  }
  return STK_OK;
}

void read_page() {
  char result = (char)STK_FAILED;
  int length = 256 * getch();
  length += getch();
  char memtype = getch();
  if (CRC_EOP != getch()) {
    error++;
    SERIAL.print((char) STK_NOSYNC);
    return;
  }
  SERIAL.print((char) STK_INSYNC);
  if (memtype == 'F') result = flash_read_page(length);
  if (memtype == 'E') result = eeprom_read_page(length);
  SERIAL.print(result);
}

void read_signature() {
  if (CRC_EOP != getch()) {
    error++;
    SERIAL.print((char) STK_NOSYNC);
    return;
  }
  SERIAL.print((char) STK_INSYNC);
  uint8_t high = spi_transaction(0x30, 0x00, 0x00, 0x00);
  SERIAL.print((char) high);
  uint8_t middle = spi_transaction(0x30, 0x00, 0x01, 0x00);
  SERIAL.print((char) middle);
  uint8_t low = spi_transaction(0x30, 0x00, 0x02, 0x00);
  SERIAL.print((char) low);
  SERIAL.print((char) STK_OK);
}
//////////////////////////////////////////
//////////////////////////////////////////


////////////////////////////////////
////////////////////////////////////
void avrisp() {
  uint8_t ch = getch();
  switch (ch) {
    case '0': // signon
      error = 0;
      empty_reply();
      break;
    case '1':
      if (getch() == CRC_EOP) {
        SERIAL.print((char) STK_INSYNC);
        SERIAL.print("AVR ISP");
        SERIAL.print((char) STK_OK);
      }
      else {
        error++;
        SERIAL.print((char) STK_NOSYNC);
      }
      break;
    case 'A':
      get_version(getch());
      break;
    case 'B':
      fill(20);
      set_parameters();
      empty_reply();
      break;
    case 'E': // extended parameters - ignore for now
      fill(5);
      empty_reply();
      break;
    case 'P':
      if (!pmode)
        start_pmode();
      empty_reply();
      break;
    case 'U': // set address (word)
      here = getch();
      here += 256 * getch();
      empty_reply();
      break;

    case 0x60: //STK_PROG_FLASH
      getch(); // low addr
      getch(); // high addr
      empty_reply();
      break;
    case 0x61: //STK_PROG_DATA
      getch(); // data
      empty_reply();
      break;

    case 0x64: //STK_PROG_PAGE
      program_page();
      break;

    case 0x74: //STK_READ_PAGE 't'
      read_page();
      break;

    case 'V': //0x56
      universal();
      break;
    case 'Q': //0x51
      error = 0;
      end_pmode();
      empty_reply();
      break;

    case 0x75: //STK_READ_SIGN 'u'
      read_signature();
      break;

    // expecting a command, not CRC_EOP
    // this is how we can get back in sync
    case CRC_EOP:
      error++;
      SERIAL.print((char) STK_NOSYNC);
      break;

    // anything else we will return STK_UNKNOWN
    default:
      error++;
      if (CRC_EOP == getch())
        SERIAL.print((char)STK_UNKNOWN);
      else
        SERIAL.print((char)STK_NOSYNC);
  }
}

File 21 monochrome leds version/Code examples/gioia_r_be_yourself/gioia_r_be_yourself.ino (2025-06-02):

/*
 GIOIA - glittering fashion

gioia_r_be_yourself.ino

Text animations for Gioia 21 monochrome leds type
Date 24/05/2025 created by Sergio Ghirardelli (first release)

*/

int enablepin = 1; //pin5 (PWM)
int latchPin = 3; //pin2
int clockPin = 4; //pin3
int dataPin = 0; //pin6
int butPin = 2;
long randNumber;
bool pippo;
uint32_t led;
int k;
int j;
int n0;
int rain0,rain1,rain2,rain3,rain4;
bool h0;
bool but, but_p, but_mem;
int prog;
bool paint;
bool start;

//oscillator 0
unsigned long t0;
unsigned long speed0;
bool a0,b0;

//oscillator 1
unsigned long t1;
unsigned long speed1;
bool a1,b1;


//pos trig0
bool p0,p0_mem;

//asymmetric oscillator 
unsigned long elapsed_time2;
unsigned long count_time2; 
bool time2_q;
unsigned long elapsed_time3;
unsigned long count_time3; 
bool time3_q;
unsigned long speed2, speed3;


int y0,y1,y2,y3,y4;

void(* Riavvia)(void) = 0; //Sketch Reset procedure


//-----------------------------------------------------------------------------------------------------------

void setup() 
{
//set pins to output so you can control the shift register
pinMode(enablepin, OUTPUT);
pinMode(latchPin, OUTPUT);
pinMode(clockPin, OUTPUT);
pinMode(dataPin, OUTPUT);
pinMode(butPin, INPUT_PULLUP);
//pinMode(LED_BUILTIN, OUTPUT);
//randomSeed(analogRead(A0));
pippo = false;
prog = 1;
led = 0;
k=0;
led_clear();
paint=true;
b0=false;
t0=0;
n0=0;
rain0=-1;
rain1=-4;
rain2=0;
rain3=-3;
rain4=-2;
h0=true;
speed0=10000;
start=false;
}

//-----------------------------------------------------------------------------------------------------------

void loop()
{
//oscillator 0
a0=false;
if (millis() - t0 >= speed0) 
      {
       a0=true;
       b0=!b0;
       t0 += speed0;
      }

//oscillator 1
a1=false;
if (millis() - t1 >= speed1) 
      {
       a1=true;
       b1=!b1;
       t1 += speed1;
      }




if (prog==1) {
  speed0 = 3000;
  analogWrite(enablepin, 240);
  brilla(15,80);
  if (a0) {
    n0=0;
    prog=8;
    led_clear();
    }
}







/*
else if (prog==2) {
  speed0 = 2000;
  speed1 = 50;
  analogWrite(enablepin, 240);
  if (a1) {
       vert (n0,paint);
       n0++;
       if (n0>4) {
        n0=0;
        paint=!paint;
        }
      }
   if (a0) {
    n0=0;
    prog=3;
    led_clear();
    }
  }


else if (prog==3) {
  speed0 = 2000;
  speed1 = 50;
  analogWrite(enablepin, 240);
  if (a1) {
       oriz (n0,paint);
       n0++;
       if (n0>4) {
        n0=0;
        paint=!paint;
        }
      }
   if (a0) {
    n0=0;
    prog=4;
    led_clear();
    }
  } 

else if (prog==4) {
  speed0 = 2000;
  speed1 = 50;
  analogWrite(enablepin, 240);
  if (a1) {
       obli_sx (n0,paint);
       n0++;
       if (n0>6) {
        n0=0;
        paint=!paint;
        }
      }
   if (a0) {
    n0=0;
    prog=5;
    //led_clear();
    }
  } 

else if (prog==5) {
  speed0 = 2000;
  speed1 = 50;
  analogWrite(enablepin, 240);
  if (a1) {
       obli_dx (n0,paint);
       n0++;
       if (n0>6) {
        n0=0;
        paint=!paint;
        }
      }
   if (a0) {
    n0=0;
    prog=6;
    led_clear();
    }
  } 

else if (prog==6) {
  speed0 = 8000;
  speed1 = 80;
  
  if (a1) {
       int dim;
       if (h0) {dim =254-n0;}
       else {dim =245+n0;}
       analogWrite(enablepin, dim);
       led_full();       
       n0++;
       if (n0>10) {
        n0=0;
        h0=!h0;
        }
      }
   if (a0) {
    n0=0;
    prog=7;
    led_clear();
    }
  } 

else if (prog==7) {
  speed0 = 10000;
  unsigned long rain_speed = 75;
  rain(0,rain0,rain_speed,false);
  rain(1,rain1,rain_speed,false);
  rain(2,rain2,rain_speed,false);
  rain(3,rain3,rain_speed,false);
  rain(4,rain4,rain_speed,false);
   if (a0) {
    prog=8;
    led_clear();
    n0=0;
    }
  } */

else if (prog==8) {
  speed2 = 750;
  speed3 = 100;
  speed0 = (speed2+speed3)*12 ;
  //asymmetric oscillator 
  time2_q = TON (!time3_q, speed2, elapsed_time2, count_time2);
  time3_q = TON (time2_q, speed3, elapsed_time3, count_time3);
  p0 =  PosTrig (time2_q, p0_mem);
  analogWrite(enablepin, 240);
  if (time3_q) {
         if (n0==0) {_B();}
         else if (n0==1) {_E();}
         else if (n0==2) {led_clear();}
         else if (n0==3) {_Y();}
         else if (n0==4) {_O();}
         else if (n0==5) {_U();}
         else if (n0==6) {_R();}
         else if (n0==7) {_S();}
         else if (n0==8) {_E();}
         else if (n0==9) {_L();}
         else if (n0==10) {_F();}
         else if (n0==11) {_esclamativo();}
         n0++;
         }
   if (p0) {led_clear();}
  if (a0) {
  prog=1;
  led_clear();
  n0=0;
  }
       
  } 

}

//-----------------------------------------------------------------------------------------------------------

void led_clear() {
  led = 0;
  exec(); 
}

//-----------------------------------------------------------------------------------------------------------

void led_full() {
  led = 16777215;
  exec(); 
}

//-----------------------------------------------------------------------------------------------------------

void pix (int x, int y, bool s) {
  int who [5][5] {
        {1,4,14,13,2},
        {0,5,11,8,15},
        {7,6,12,10,9},
        {19,17,21,23,16},
        {3,22,20,18,1},
        };
  int who_is = who[y][x];
  if (s) {
         bitSet (led,who_is);
         exec();
         }
  else {
        bitClear (led,who_is);
        exec();
        }
}

//-----------------------------------------------------------------------------------------------------------

void vert (int x, bool s) {
    for (int j = 0; j < 5; j++) {
    pix (x,j,s);
    exec(); 
    }
}

//-----------------------------------------------------------------------------------------------------------

void oriz (int y, bool s) {
  for (int j = 0; j < 5; j++) {
    pix (j,y,s);
    exec();
  }
}

//-----------------------------------------------------------------------------------------------------------

void obli_sx (int j, bool s) {
  if (j==0) { 
    pix(0,1,s);
    pix(1,0,s);
    }
  if (j==1) { 
    pix(0,2,s);
    pix(1,1,s);
    pix(2,0,s);
    }
  if (j==2) { 
    pix(0,3,s);
    pix(1,2,s);
    pix(2,1,s);
    pix(3,0,s);
    }
    if (j==3) { 
    pix(1,3,s);
    pix(2,2,s);
    pix(3,1,s);
    }
    if (j==4) { 
    pix(1,4,s);
    pix(2,3,s);
    pix(3,2,s);
    pix(4,1,s);
    }
    if (j==5) { 
    pix(2,4,s);
    pix(3,3,s);
    pix(4,2,s);
    }
    if (j==6) { 
    pix(3,4,s);
    pix(4,3,s);
    }
  exec();
}

//-----------------------------------------------------------------------------------------------------------
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

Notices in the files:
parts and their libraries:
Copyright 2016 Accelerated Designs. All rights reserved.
